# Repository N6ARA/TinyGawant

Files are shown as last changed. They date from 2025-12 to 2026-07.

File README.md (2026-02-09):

# TinyGawant

TinyGawant Antenna Project - A minature QRP antenna with a built-in tuner and SWR indicator.

[N6ARA Product Page - TinyGawant](https://n6ara.com/product/tinygawant-kit/)

# Build

## Board Files

See Gerber Files in [PCB/TinyGawant](/PCB/TinyGawant) Folder

## Bill of Materials

See [BOM](/BOM) Folder

## 3D Print Files

See [3D Printables](/3D%20Printables/) Folder

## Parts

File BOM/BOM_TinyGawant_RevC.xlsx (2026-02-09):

Reference | Value | Qty | MPN | Cost per Unit | Link
C2,C3 | 0.01 | 2 | GMC21X7R103J50NT | $0.20 | https://www.digikey.com/en/products/detail/cal-chip-electronics-inc/GMC21X7R103J50NT/22577164
D1 | 750-CDBW46-G | 1 | CDBW46-G | $0.26 | https://www.digikey.com/en/products/detail/comchip-technology/CDBW46-G/3308556
D2 | RED | 1 | 156125RS57000 | $0.42 | https://www.digikey.com/en/products/detail/würth-elektronik/156125RS57000/9857918
D3 | TZMC3V3-GS08 | 1 | TZMC3V3-GS08 | $0.13 | https://www.digikey.com/en/products/detail/vishay-general-semiconductor-diodes-division/TZMC3V3-GS08/3104272
J2,J3 | 7695-3 | 2 | 7790 | $1.28 | https://www.digikey.com/en/products/detail/keystone-electronics/7790/2171010
R1,R2,R4 | 50 | 3 | CRM2512-FX-51R0ELF | $1.56 | https://www.digikey.com/en/products/detail/bourns-inc/CRM2512-FX-51R0ELF/4698407
R3 | 1k | 1 | RC0805FR-071KL | $0.12 | https://www.digikey.com/en/products/detail/yageo/RC0805FR-071KL/727444
SW1 | SW_DPDT_x2 | 1 | JS202011AQN | $0.75 | https://www.digikey.com/en/products/detail/c-k/JS202011AQN/1640096
SW2 | SW_SPDT | 1 | JS102011SAQN | $0.76 | https://www.digikey.com/en/products/detail/c-k/JS102011SAQN/1640095
C1 |  | 1 | CBM-443BF | $2.00 | https://www.aliexpress.us/item/2255800609195661.html?curPageLogUid=80i4KDQZDI0j
T1 |  | 1 | T50-6 | $1.57 | https://www.amidoncorp.com/t50-6/
J1 |  | 1 | BNC Thru Hole Plug male Vertical PCB Mount Straight RF Coax ADAPTER | $1.00 | https://www.aliexpress.us/item/2251832111232237.html
PCB |  | 1 | JLCPCB | $1.00 | Get quote at JLCPCB
24AWG Red Enamel Wire |  | 1 |  | - | https://www.amazon.com/BNTECHGO-AWG-Magnet-Wire-Transformers/dp/B07DYHWLN4
26AWG Green Enamel Wire |  | 1 |  | - | https://www.amazon.com/BNTECHGO-AWG-Magnet-Wire-Transformers/dp/B07HRKKMPS?sp_csd=d2lkZ2V0TmFtZT1zcF9tdGY
Antenna |  | 1 | M3 Male Thread Screw On Telescopic Antenna 7 Sections 97.3CM | $1.88 | https://www.aliexpress.us/item/2251832701726364.html
Thumb Screw |  | 1 | M3x6mm(DXL) Knurled Thumb Screws | $0.90 | https://www.amazon.com/dp/B0BZRM6ZYM?ref_=ppx_hzsearch_conn_dt_b_fed_asin_title_9&th=1
M2.5x10mm |  | 2 | M2.5x10mm | $0.10 | https://www.amazon.com/iexcell-Thread-Stainless-Socket-Screws/dp/B0D7S1CFY4?s=industrial
M2.5x6mm |  | 2 | M2.5x6mm | $0.20 | https://www.amazon.com/iexcell-Thread-Stainless-Socket-Screws/dp/B0D7S1CM87?s=industrial
M3 x 12mm |  | 3 | M3 x 12mm | $0.30 | https://www.amazon.com/iexcell-Thread-Stainless-Socket-Screws/dp/B089KSQRQQ?s=industrial
3D Print Files |  | 1 | See "3D Printables" Folder | - | See "3D Printables" Folder
Total |  |  |  | $14.43 | (per board at volume, total cost may vary minimum quantity buy and shipping)

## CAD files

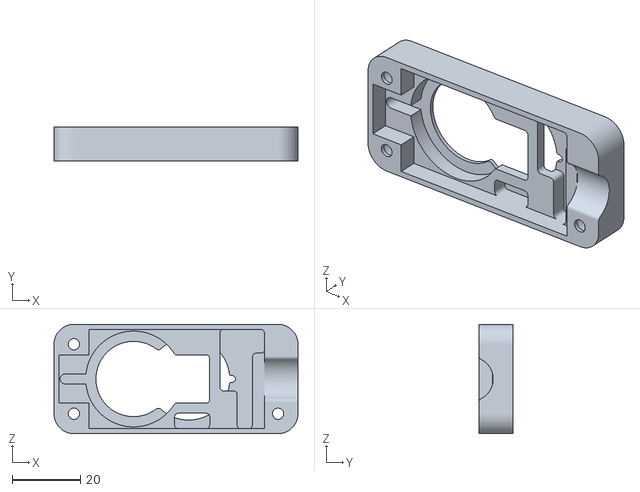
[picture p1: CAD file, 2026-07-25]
3D Printables/TinyGawant_FrontCover_Color.stl
71.3 x 10.0 x 31.9

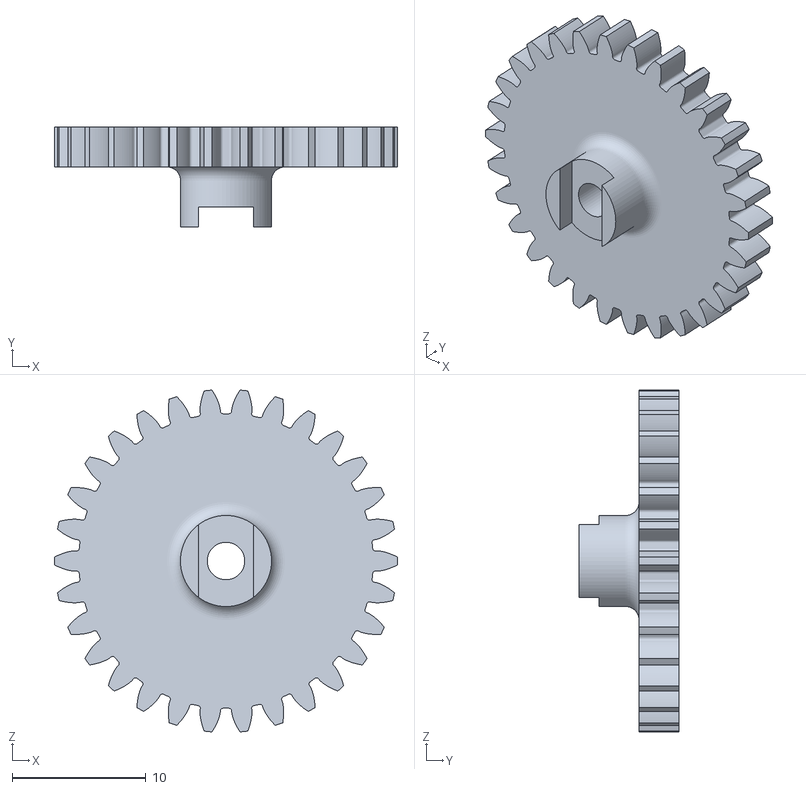
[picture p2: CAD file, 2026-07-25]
3D Printables/Cap_Gear_Color.stl
25.6 x 7.50 x 25.5

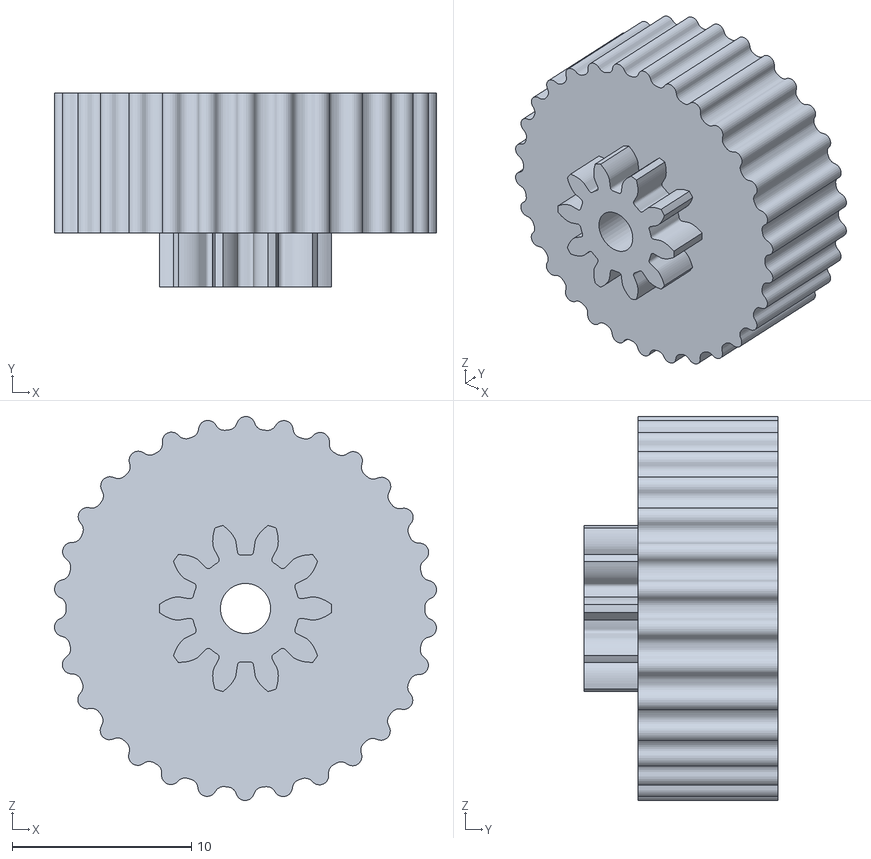
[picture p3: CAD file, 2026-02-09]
3D Printables/Knob_Gear v7.stl
21.3 x 10.8 x 21.4

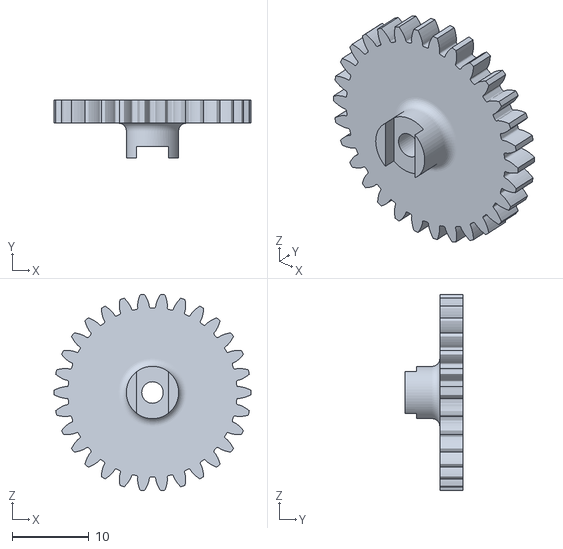
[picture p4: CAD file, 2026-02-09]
3D Printables/Cap_Gear v17.stl
25.6 x 7.50 x 25.5

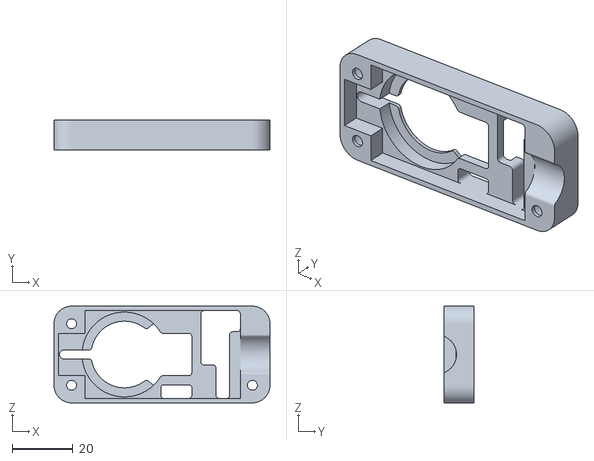
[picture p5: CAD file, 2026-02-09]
3D Printables/TinyGawant_FrontCover v37.stl
71.3 x 10.0 x 31.9

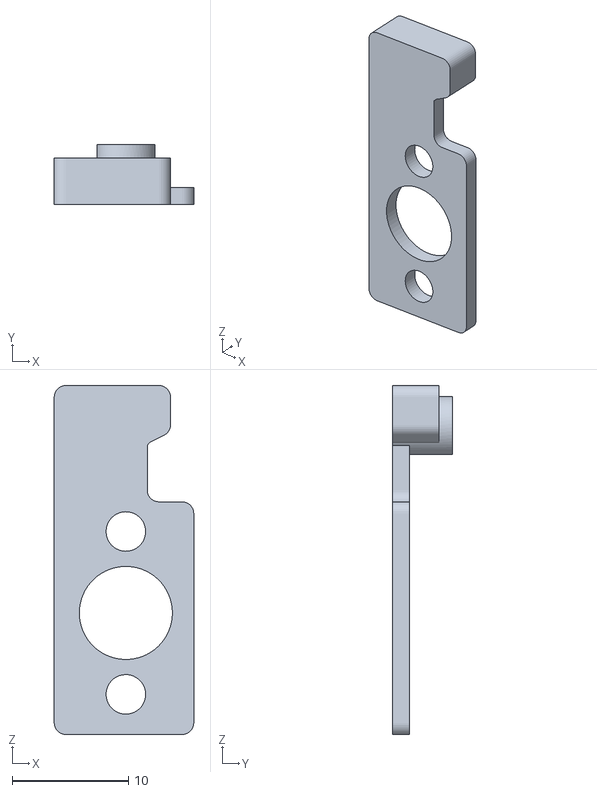
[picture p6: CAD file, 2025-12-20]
3D Printables/Gear_Frame v18.stl
12.0 x 5.20 x 30.0

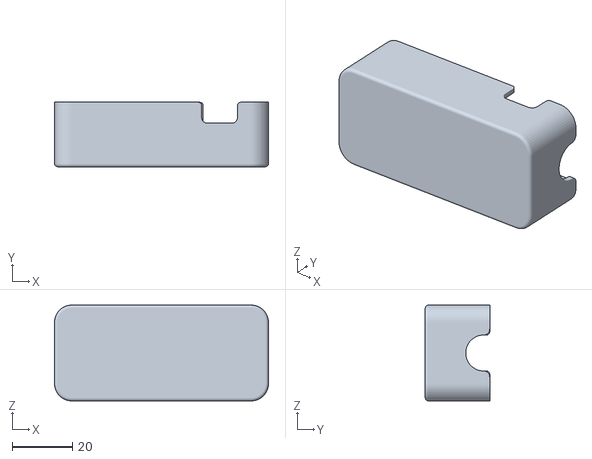
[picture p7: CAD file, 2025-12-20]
3D Printables/TinyGawant_BackEnclosure v18.stl
71.3 x 21.5 x 31.9

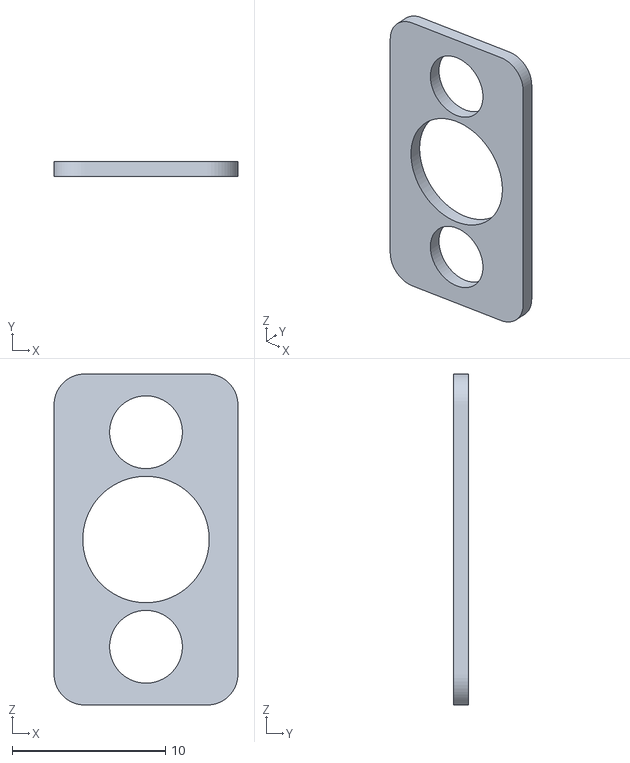
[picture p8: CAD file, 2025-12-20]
3D Printables/Polyvaricon Spacer v5.stl
12.0 x 1.00 x 21.6

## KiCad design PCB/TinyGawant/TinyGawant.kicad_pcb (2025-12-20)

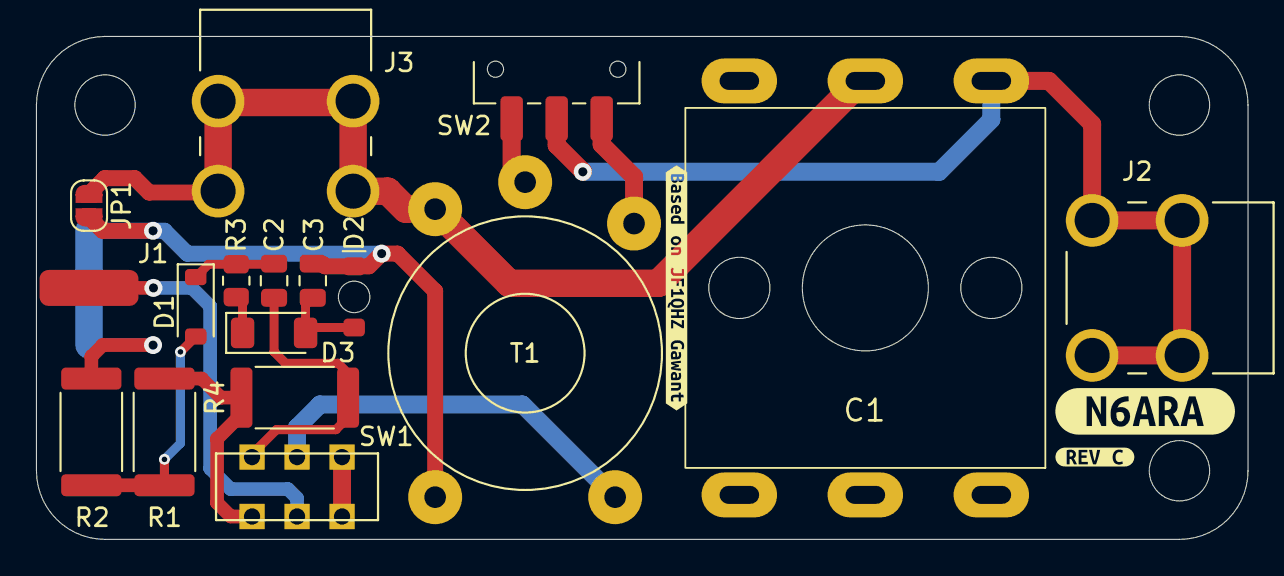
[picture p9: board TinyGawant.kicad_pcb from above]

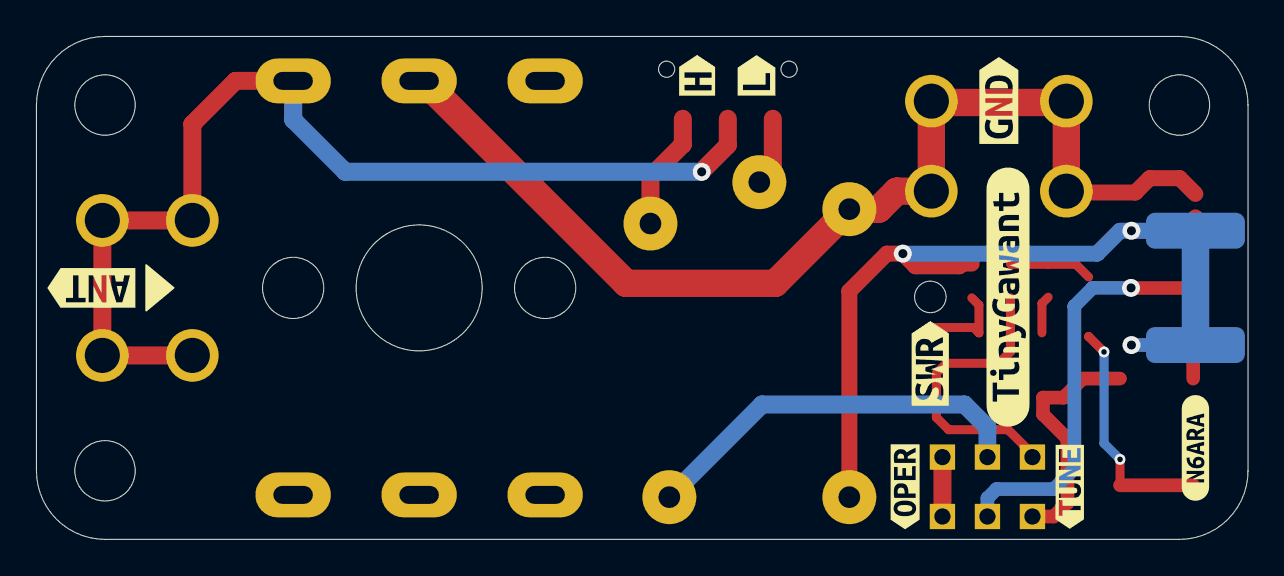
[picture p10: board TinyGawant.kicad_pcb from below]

Board: 2 copper layers, 67.3 x 27.9 mm, 29 parts (9 on the bottom side), 14 nets.

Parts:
C1: Polyvaricon_Capacitor
C2, C3: 0.01; C_0805_2012Metric
D1: 750-CDBW46-G; D_SOD-123
D2: RED; WL-SMRD-Bottom-Mount
D3: TZMC3V3-GS08; D_MiniMELF
J1: Conn_Coaxial; BNC_Edge
J2, J3: 7695-3; KEYSTONE_7695-3
JP1: Jumper_2_Bridged; SolderJumper-2_P1.3mm_Open_RoundedPad1.0x1.5mm
R1, R2, R4: 50; R_2512_6332Metric
R3: 1k; R_0805_2012Metric
SW1: SW_DPDT_x2; JS202011AQN
SW2: SW_SPDT; SW_SPDT_CK_JS102011SAQN
T1: Transformer_1P_SS; Transformer_Toroid_Horizontal_D14.0mm_Amidon-T50_3_2
kibuzzard-675A8744: G***; kibuzzard-675A8744
kibuzzard-676A6A04: G***; kibuzzard-676A6A04
kibuzzard-6922A9F4: G***; kibuzzard-6922A9F4
kibuzzard-6923ECB0: G***; kibuzzard-6923ECB0
kibuzzard-6923ED1D: G***; kibuzzard-6923ED1D
kibuzzard-6923F3E6: G***; kibuzzard-6923F3E6
kibuzzard-6923F404: G***; kibuzzard-6923F404
kibuzzard-677780D3: G***; kibuzzard-677780D3
kibuzzard-692298D5: G***; kibuzzard-692298D5
kibuzzard-692298E1: G***; kibuzzard-692298E1
kibuzzard-67778075: G***; kibuzzard-67778075
kibuzzard-69227399: G***; kibuzzard-69227399

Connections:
GND: C3.2, D2.1 (K), J1.2 (Ext), JP1.2 (B), R2.2, T1.1 (AA)
unnamed: D1.2 (A), R1.2, R2.1
unnamed: C2.2, D1.1 (K), R3.1
unnamed: C3.1, D2.2 (A), D3.2 (A)
unnamed: D3.1 (K), R3.2
unnamed: J1.1 (In), SW1.2 (B)
unnamed: C1.4, J2.1, J2.2 (1__1), J2.3 (1__2), J2.4 (1__3), SW2.2 (B)
unnamed: R1.1, R4.2, SW1.1 (A)
unnamed: SW1.3 (C), SW1.6 (C)
unnamed: C2.1, R4.1, SW1.4 (A)
unnamed: SW1.5 (B), T1.2 (AB)
unnamed: SW2.1 (A), T1.4 (SC)
unnamed: SW2.3 (C), T1.3 (SA)
RFGND: C1.2, C1.5, J3.1, J3.2 (1__1), J3.3 (1__2), J3.4 (1__3), JP1.1 (A), T1.5 (SB)

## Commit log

2025-12-20 Initial Commit - Production Rev C
    [BOM_TinyGawant_RevC.xlsx, Cap_Gear v13.stl, Gear_Frame v18.stl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]
2025-12-20 added super basic instructions
    [BOM_TinyGawant_RevC.xlsx]
2026-02-09 Update to Rev C Production
    [BOM_TinyGawant_RevC.xlsx, Cap_Gear v13.stl, Cap_Gear v17.stl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]
2026-07-25 Added color cap gear and front cover. Print with 0.2mm nozzle.
    [Cap_Gear_Color.stl, TinyGawant_FrontCover_Color.stl]
